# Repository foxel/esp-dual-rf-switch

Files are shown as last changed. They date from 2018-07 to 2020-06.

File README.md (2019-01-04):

# LightFox Dual - ESP8266 Dual RF switch for lights

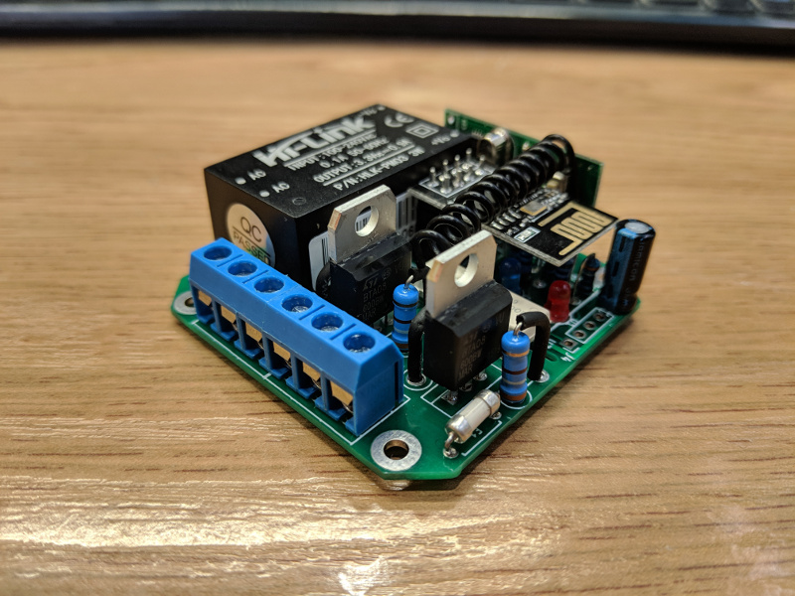
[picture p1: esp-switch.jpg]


## Connecting the board

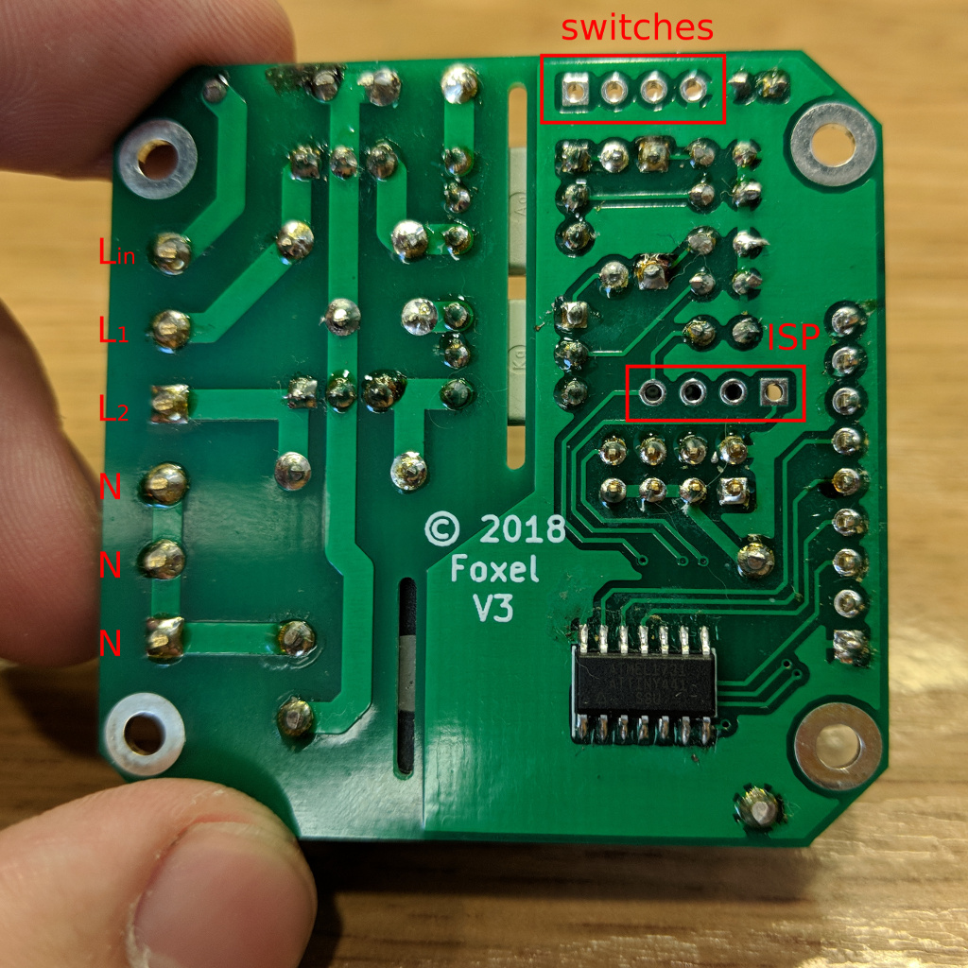
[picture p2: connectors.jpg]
connectors


The board has following connectors:
* mains connector with sqrew terminals (`Lin`, `L1`, `L2`, `N`). Mains supply should be connected to `Lin` and one of `N` terminals. The loads are connected to `L1`/`L2` and one of `N` terminals.
* ISP connector for ATTiny flashing. Pins are (from left to right): `RST`, `MOSI`, `MISO`, `SCL`)
* switches output connector for debug, etc. These are connected to ATTiny outputs controlling triacs. Pins are (from left to right): `L1`, `L2`, `3V3`, `GND`.

## Schematics

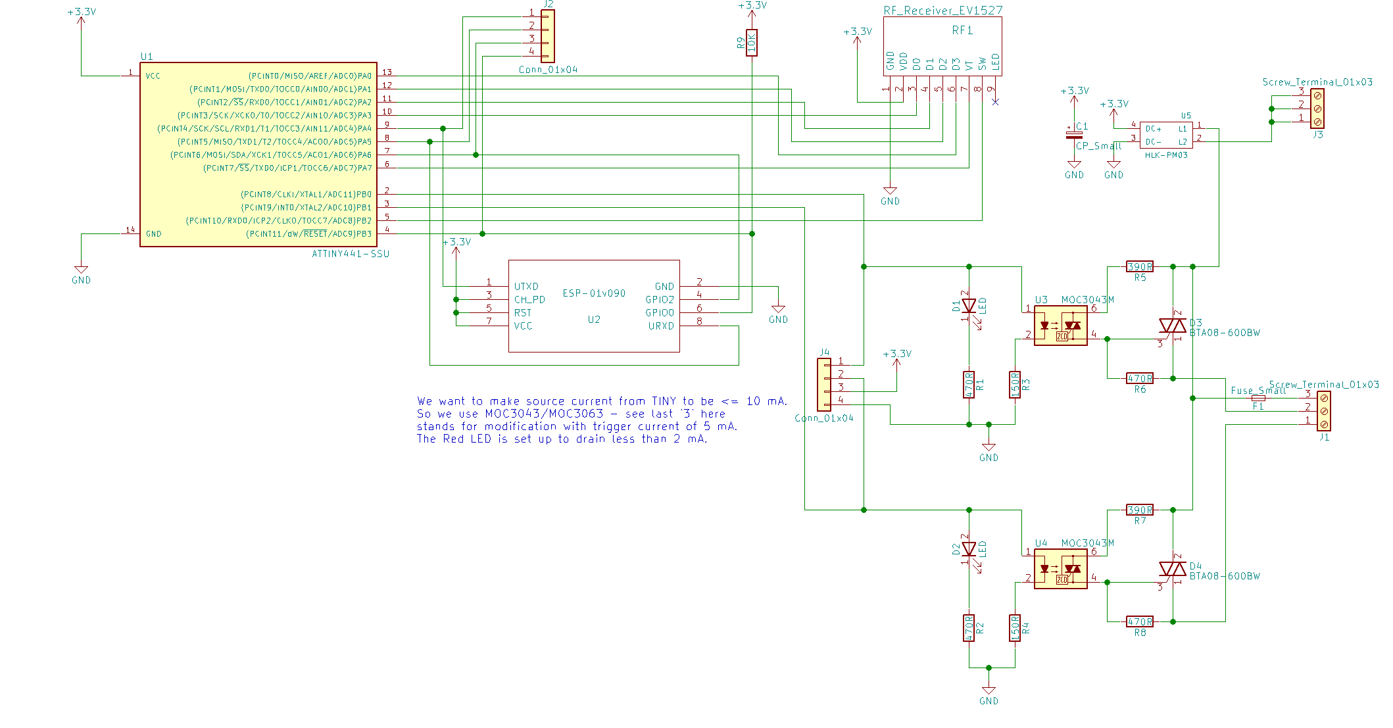
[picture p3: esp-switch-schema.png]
shematics


## Layout

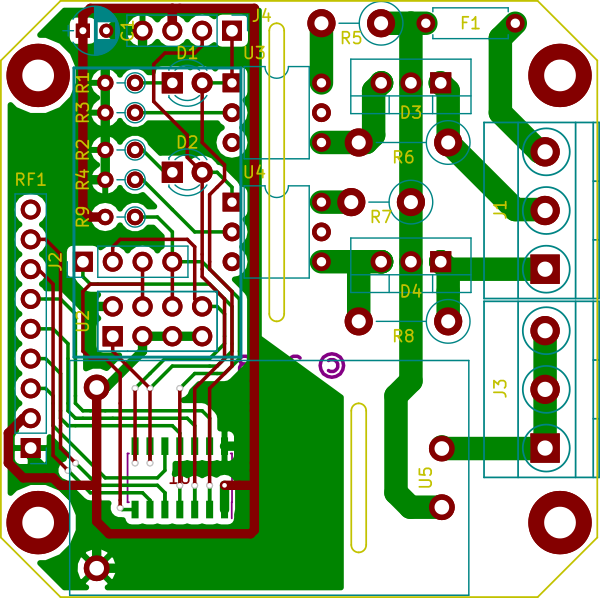
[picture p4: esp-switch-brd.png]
Board layout


## Firmware

There are two microcontrollers to run this switch
* **ESP-01** - use one of available firmware options:
  * ESPurna firmware: https://github.com/foxel/espurna/tree/lightfox-dual
  * Tasmota firmware: https://github.com/foxel/Sonoff-Tasmota/tree/foxel_dual_rf

* **ATTINY441** - firmware is in `attiny-firmware` folder. This requires [ATTinyCore](https://github.com/SpenceKonde/ATTinyCore) to build

To flash ESP module connect it to PC any available way (e.g. USB-Serail adapter + breadboard) and follow selected firmware option flashing instructions.

To flash ATTINY:
* remove ESP-01 module from the header
* connect ISP programmer (i.e. Arduino flashed with ArduinoISP) to ISP port
* use Arduino to flash MC: board is ATTiny441 (installed from [ATTinyCore](https://github.com/SpenceKonde/ATTinyCore))

## BOM

Item | Qty | Reference(s) | Link
-----|-----|--------------|------
100uF, 5v | 1 | C1 | 
3mm red LED | 2 | D1, D2 | 
BTA08-600BW | 2 | D3, D4 | 
1A fuse | 1 | F1 | 
Screw Terminal 01x03 | 2 | J1, J3 | 
4pin header | 2 | J2, J4 | 
470R, 0.125W | 2 | R1, R2 | 
150R, 0.125W | 2 | R3, R4 | 
390R, 0.5W | 2 | R5, R7 | 
470R, 0.5W | 2 | R6, R8 | 
10K, 0.125W | 1 | R9 | 
Itead.cc RF receiver | 1 | RF1 | https://www.itead.cc/rf-receiver-module-433mhz.html
ATTINY441-SSU | 1 | U1 | 
ESP-01S | 1 | U2 | 
MOC3043M/MOC3063M | 2 | U3, U4 | 
HLK-PM03 | 1 | U5 |

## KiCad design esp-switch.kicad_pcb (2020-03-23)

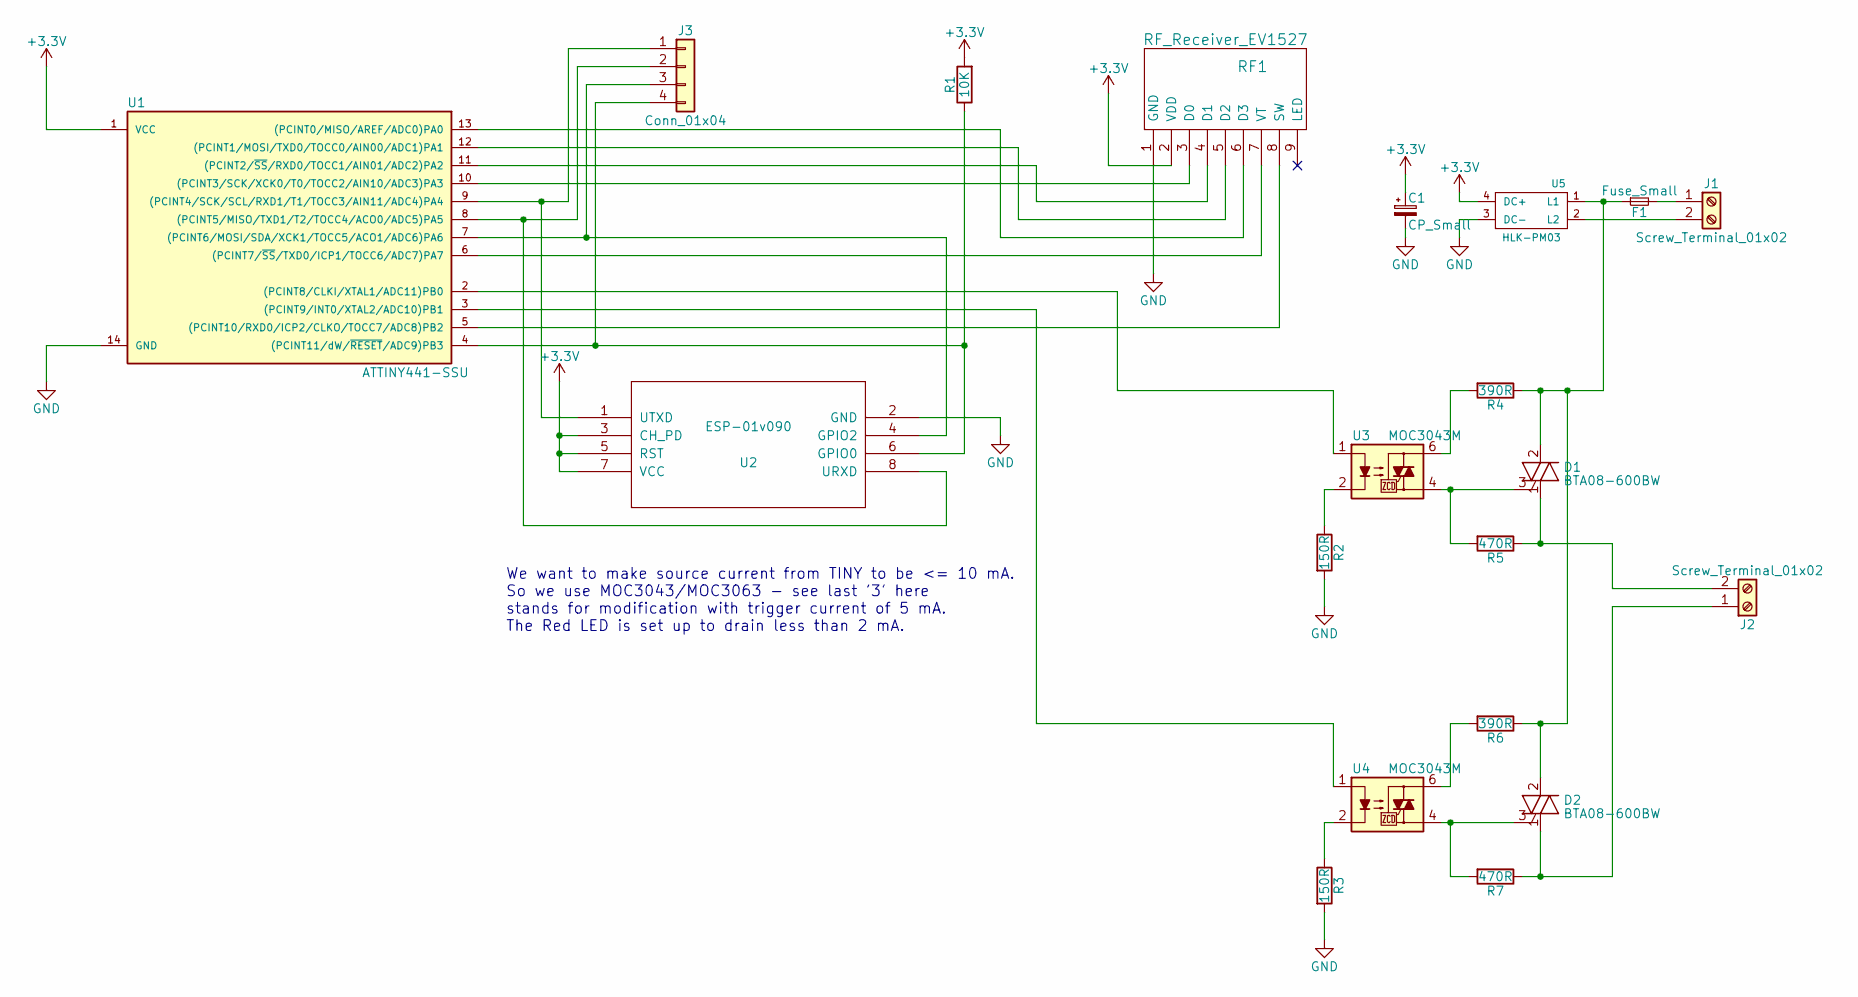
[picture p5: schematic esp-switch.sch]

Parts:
C1: CP_Small; CP_Radial_D4.0mm_P2.00mm
D1, D2: BTA08-600BW; TO-220_Vertical
F1: Fuse_Small; R_Axial_DIN0207_L6.3mm_D2.5mm_P7.62mm_Horizontal
J1, J2: Screw_Terminal_01x02; TerminalBlock_Pheonix_MKDS1.5-2pol
J3: Conn_01x04; Pin_Header_Straight_1x04_Pitch2.54mm
R1: 10K; R_Axial_DIN0204_L3.6mm_D1.6mm_P2.54mm_Vertical
R2, R3: 150R; R_Axial_DIN0204_L3.6mm_D1.6mm_P2.54mm_Vertical
R4, R6: 390R; R_Axial_DIN0207_L6.3mm_D2.5mm_P5.08mm_Vertical
R5, R7: 470R; R_Axial_DIN0207_L6.3mm_D2.5mm_P5.08mm_Vertical
RF1: RF_Receiver_EV1527; RF_Receiver_Decoder
U1: ATTINY441-SSU; SOIC-14_3.9x8.7mm_Pitch1.27mm
U2: ESP-01v090; ESP-01
U3, U4: MOC3043M; DIP-6_W7.62mm
U5: HLK-PM03; HLK-PM05

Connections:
+3V3: C1.1, R1.2, RF1.2 (VDD), U1.1 (VCC), U2.3 (CH_PD), U2.5 (RST), U2.7 (VCC), U5.4 (DC+)
GND: C1.2, R2.2, R3.2, RF1.1 (GND), U1.14 (GND), U2.2 (GND), U5.3 (DC-)
unnamed: D1.1 (T1), J2.2, R5.1
unnamed: D1.2 (T2), D2.2 (T2), F1.1, R4.1, R6.1, U5.1 (L1)
unnamed: D1.3 (G), R5.2, U3.4
unnamed: D2.1 (T1), J2.1, R7.1
unnamed: D2.3 (G), R7.2, U4.4
unnamed: F1.2, J1.1
unnamed: J1.2, U5.2 (L2)
unnamed: J3.1, U1.9 ((PCINT4/SCK/SCL/RXD1/T1/TOCC3/AIN11/ADC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), U2.1 (UTXD)
unnamed: J3.2, U1.8 ((PCINT5/MISO/TXD1/T2/TOCC4/ACO0/ADC5)PA5), U2.8 (URXD)
unnamed: J3.3, U1.7 ((PCINT6/MOSI/SDA/XCK1/TOCC5/ACO1/ADC6)P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), U2.4 (GPIO2)
unnamed: J3.4, R1.1, U1.4 ((PCINT11/dW/~RESET~/ADC9)PB3), U2.6 (GPIO0)
unnamed: R2.1, U3.2
unnamed: R3.1, U4.2
unnamed: R4.2, U3.6
unnamed: R6.2, U4.6
unnamed: RF1.3 (D0), U1.10 ((PCINT3/SCK/XCK0/T0/TOCC2/AIN10/ADC3)PA3)
unnamed: RF1.4 (D1), U1.11 ((PCINT2/~SS~/RXD0/TOCC1/AIN01/ADC2)PA2)
unnamed: RF1.5 (D2), U1.12 ((PCINT1/MOSI/TXD0/TOCC0/AIN00/ADC1)PA1)
unnamed: RF1.6 (D3), U1.13 ((PCINT0/MISO/AREF/ADC0)PA0)
unnamed: RF1.7 (VT), U1.6 ((PCINT7/~SS~/TXD0/ICP1/TOCC6/ADC7)PA7)
unnamed: RF1.8 (SW), U1.5 ((PCINT10/RXD0/ICP2/CLKO/TOCC7/ADC8)PB2)
unnamed: U1.2 ((PCINT8/CLKI/XTAL1/ADC11)PB0), U3.1
unnamed: U1.3 ((PCINT9/INT0/XTAL2/ADC10)PB1), U4.1

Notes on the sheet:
We want to make source current from TINY to be <= 10 mA. So we use MOC3043/MOC3063 - see last '3' here stands for modification with trigger current of 5 mA. The Red LED is set up to drain less than 2 mA.

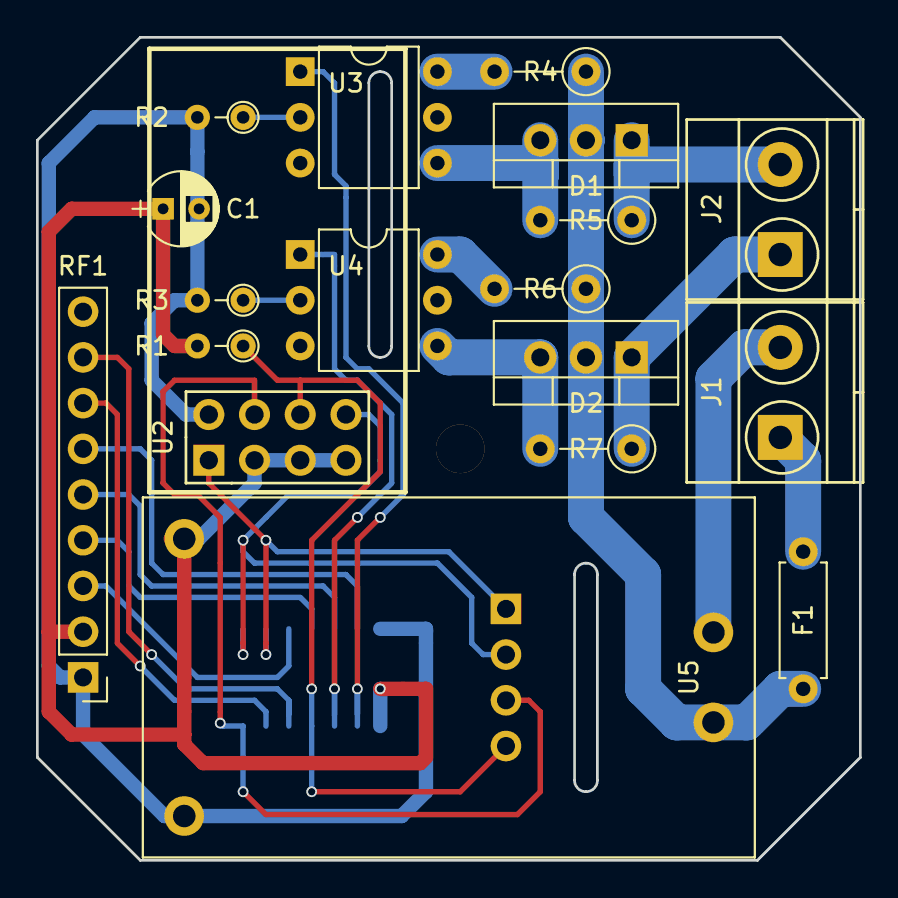
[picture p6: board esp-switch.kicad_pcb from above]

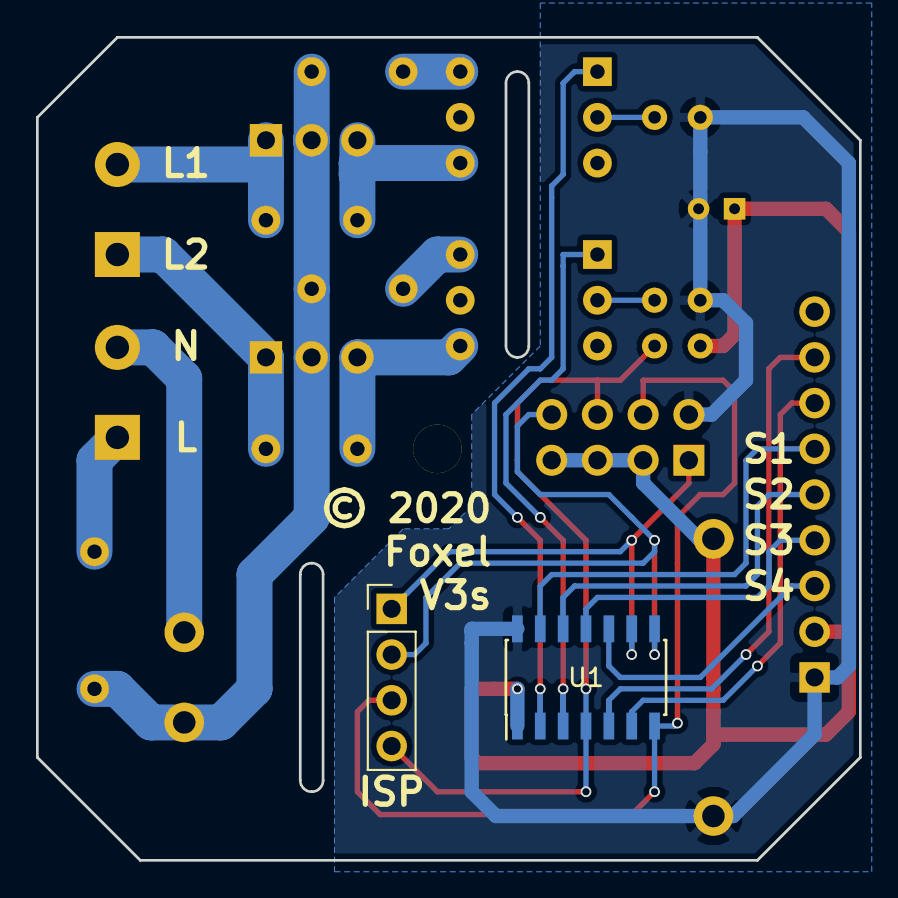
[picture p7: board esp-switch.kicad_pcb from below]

Board: 2 copper layers, 45.7 x 45.7 mm, 20 parts (2 on the bottom side), 25 nets.

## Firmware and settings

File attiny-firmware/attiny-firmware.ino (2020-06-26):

#define TASKER_MAX_TASKS 2
#include "Tasker.h"
// WALL_SWITCH_MODE should be used when RF block is replaced with wall switch connected to ground and S1-S4 pins
//#define WALL_SWITCH_MODE

Tasker tasker;

volatile byte buttonPressed = 0x00;
#ifdef WALL_SWITCH_MODE
volatile byte state = 0x00;
volatile byte newState = 0x00;
#endif
byte iCmdCode = 0x00;
byte iArgument = 0x00;
byte iStep = 0;

void setup() {
  DDRB = 0x03 | 0x04; // loads | RF SW
  PORTB = 0x00 | 0x04; // loads | RF SW

  DDRA = 0x00;
  PUEA = 0x0f;

  #ifdef WALL_SWITCH_MODE
  state = 0x0f & ~PINA;
  #endif

  GIMSK |= _BV(PCIE0);
  PCMSK0 = _BV(PCINT0) | _BV(PCINT1) | _BV(PCINT2) | _BV(PCINT3);

  Serial1.begin(19200);
}

ISR(PCINT0_vect) {
  #ifdef WALL_SWITCH_MODE
  newState = 0x0f & ~PINA;
  tasker.cancel(fix_state);
  tasker.setTimeout(fix_state, 50);
  #else
  byte state = PINA & 0x0f;
  if (state) {
    buttonPressed = state;
  }
  #endif
}

void loop() {
  tasker.loop();
  
  if (buttonPressed) {
    Serial1.write(0xA0);
    Serial1.write(0x04);
    Serial1.write(buttonPressed); 
    Serial1.write(0xA1);
    Serial1.flush();
    buttonPressed = 0x00;
  }
  
  if (Serial1.available()) {
    // read the incoming byte:
    byte incomingByte = Serial1.read();

    if (incomingByte == 0xA0) {
      iStep = 1;
    }
    else if (iStep == 1) {
      iStep = 2;
      iCmdCode = incomingByte;
    }
    else if (iStep == 2) {
      iStep = 3;
      iArgument = incomingByte;
    } else if ((iStep == 3) && (incomingByte == 0xA1)) {
      iStep = 0;
      if (iCmdCode == 0x04) { // power
        PORTB = (PORTB & 0x0C) | (iArgument & 0x03);
      }
      else if (iCmdCode == 0xF1) { // bind
        start_bind();
      }
      else if (iCmdCode == 0xF2) { // clear
        start_clear();
      }
    } else iStep = 0;
  }
}

#ifdef WALL_SWITCH_MODE
void fix_state() {
  buttonPressed = newState ^ state;
  state = newState;
}
#endif

void start_bind() {
  if (PORTB & 0x04) {
    PORTB &= ~0x04;
    tasker.setTimeout(release_rf_sw, 2500);
  }
}

void start_clear() {
  if (PORTB & 0x04) {
    PORTB &= ~0x04;
    tasker.setTimeout(release_rf_sw, 9000);
  }
}

void release_rf_sw() {
  PORTB |= 0x04;
}

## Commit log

2018-01-10 Power supply added
    [esp-switch.kicad_pcb, esp-switch.sch]
2018-01-10 Single switch source
    [esp-switch.kicad_pcb, esp-switch.sch]
2018-01-20 Complete layout
    [esp-switch.kicad_pcb, esp-switch.sch]
2018-01-23 Power circuit fuse
    [esp-switch.kicad_pcb, esp-switch.sch]
2018-01-23 Copyright moved
    [esp-switch.kicad_pcb]
2018-01-27 Some changes
    [esp-switch.kicad_pcb]
2018-01-27 V2 - traced all the channels from RF
    [esp-switch.kicad_pcb, esp-switch.sch]
2018-04-02 Added Bind and Clear commands. Changed to send raw buttons from RF to ESP
2018-04-21 Pull-Ups fixed for 441
    [attiny-firmware.ino]
2018-05-05 V3: mains with shared L and multiple N terminals programming interface for ATTINY moved so can be soldered ATTINY reset available from ESP GPIO0
    [esp-switch.kicad_pcb, esp-switch.sch]
2018-07-09 Changed components
    [esp-switch.sch]
2019-01-05 added gerber files
    [esp-switch-B.Cu.gbr, esp-switch-B.Mask.gbr, esp-switch-B.SilkS.gbr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]
2020-03-23 V4 schematics
    [esp-switch.kicad_pcb, esp-switch.sch]
2020-03-23 V4 smaller PCB
    [esp-switch.kicad_pcb, esp-switch.sch]

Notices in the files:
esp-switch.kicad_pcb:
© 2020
